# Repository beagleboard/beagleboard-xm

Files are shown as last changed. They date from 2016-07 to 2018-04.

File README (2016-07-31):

BeagleBoard-xM delivers extra ARM ® Cortex TM -A8 MHz now at 1 GHz and extra memory with 512MB of low-power DDR RAM, enabling hobbyists, innovators and engineers to go beyond their current imagination and be inspired by the BeagleBoard.org community. Designed with the community inputs in mind, this open hardware design improves upon the laptop-like performance and expandability, while keeping at hand-held power levels. Direct connectivity is supported by the on-board four-port hub with 10/100 Ethernet, while maintaining a tiny 3.25" × 3.25" footprint.

Revision C3

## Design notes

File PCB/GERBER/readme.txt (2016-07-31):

CALCAD, INC.
1600 E.PIONEER PARKWAY
SUITE # 530
ARLINGTON, TX 76010-6542
VOICE: (817)695.1806
FAX:   (817)695.1809
E-MAIL: pcb@calcad.net

CUSTOMER: CIRCUITCO
E.E. CONTACT: RAO
DATE: 08-17-2011
JOB NAME:BeagleBoard_xM_Revc1.BRD 
FAB.#: BEAGLE XM

	  FILE DESCRIPTIONS :

		 CCAM/GERBER/xM_RevC1_*:   = GERBER DATA
                      
                                     lyr1.ART  = TOP SIDE     LYR 1
                                     lyr2.ART  = GND PLANE    LYR 2
                                     lyr3.ART  = INNER SIGNAL LYR 3
                                     lyr4.ART  = INNER SIGNAL LYR 4
                                     lyr4.ART  = PWR PLANE    LYR 5
                                     lyr4.ART  = BOTTOM SIDE  LYR 6
                                     tslk.ART  = TOP SIDE SILKSCREEN
                                     bslk.ART  = BOTTOM SIDE SILKSCREEN
                                      smc.ART  = TOP SIDE SOLDERMASK
                                      sms.ART  = BOT SIDE SOLDERMASK
                                      spc.ART  = TOP SOLDERPASTE SCREEN
                                      sps.ART  = BOTTOM SOLDERPASTE SCREEN                                                                 
   
		   DRILL/*:   *NCDRILL*.TAP  = DRILL DATA

                         	  NCDRILL.LOG  = HOLE SIZES AND COUNT
			         NC_PARAM.TXT  = DRILL PARAMETER FILE                                                
                  
                    CCAM/*.CAD  = ASCII CAD FILE
                                                             
                    DXF/*.DXF  = DXF DRAWING FILE(S)

                    PDF/*.PDF  = ACROBAT DRAWING FILE(S)

                    *_XY.CMP  = COMPONENT X-Y LIST

                    *_IPC356A.IPC  = IPC-D-356A NETLIST EXTRACT

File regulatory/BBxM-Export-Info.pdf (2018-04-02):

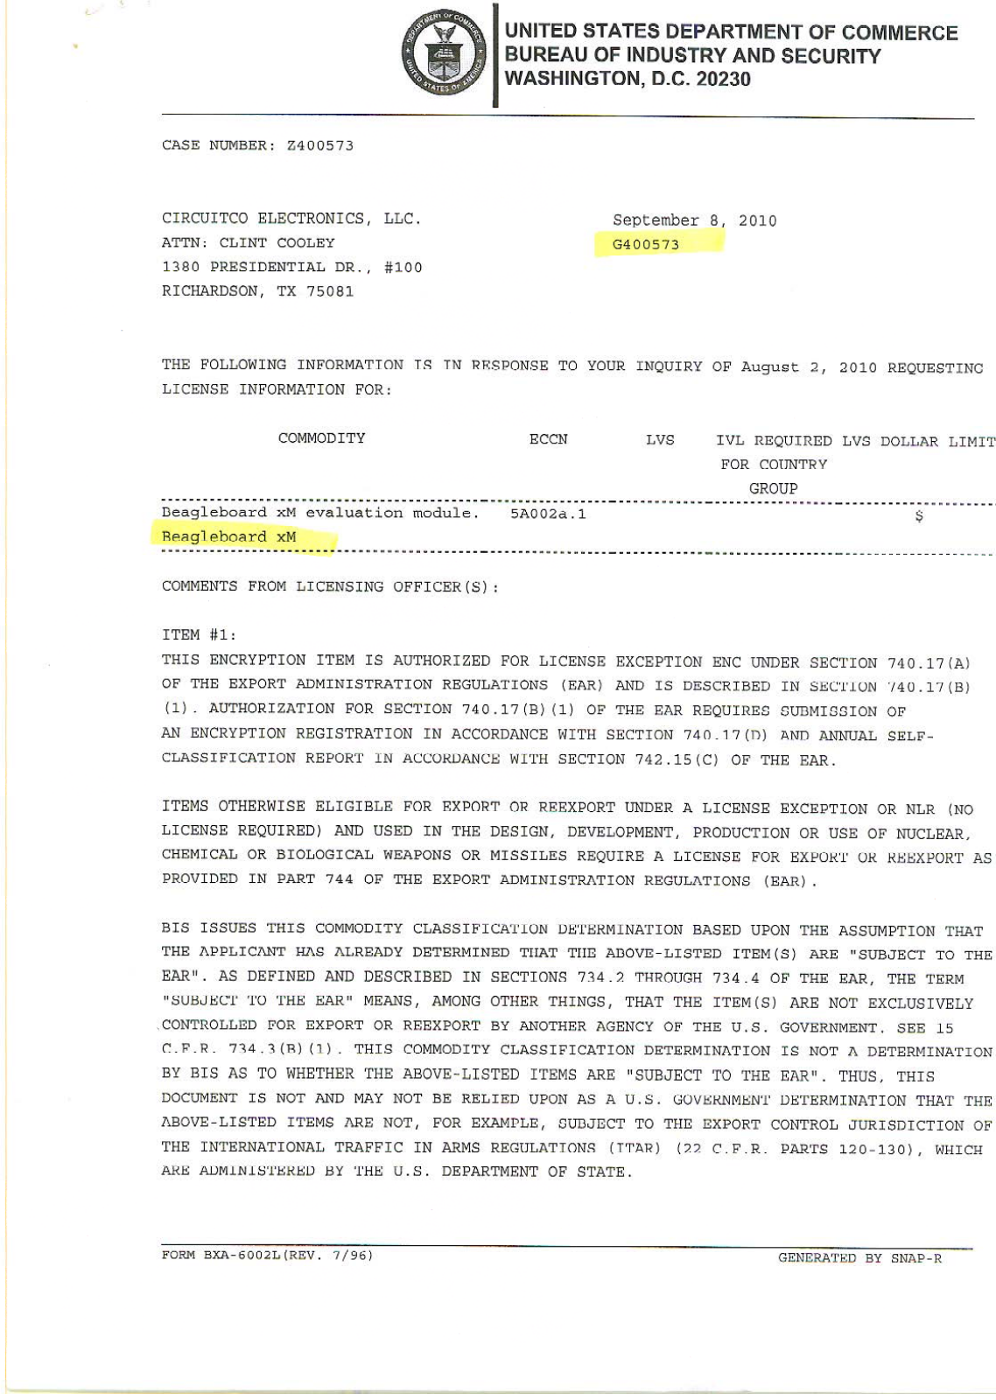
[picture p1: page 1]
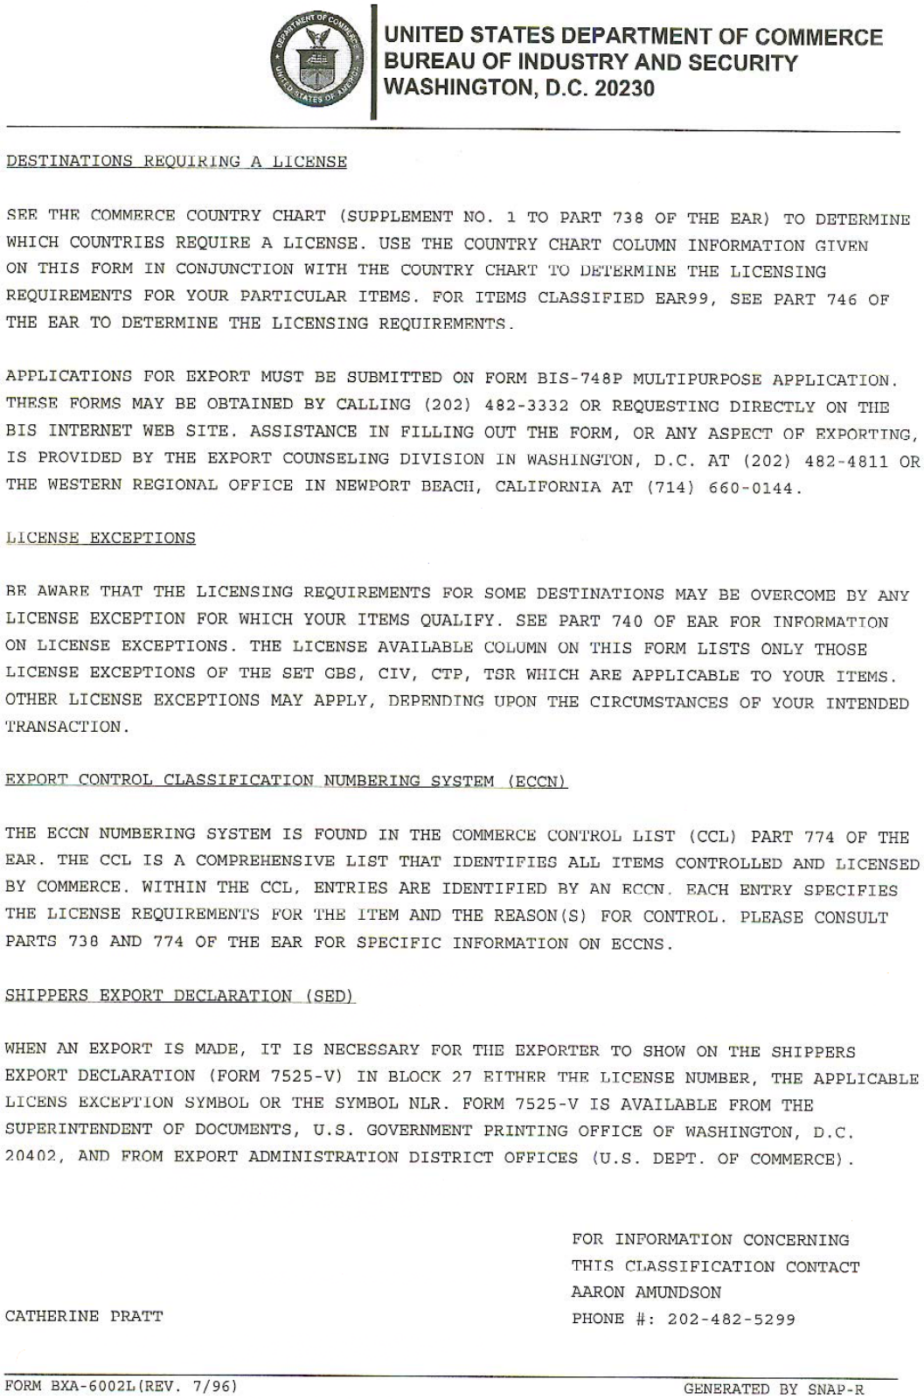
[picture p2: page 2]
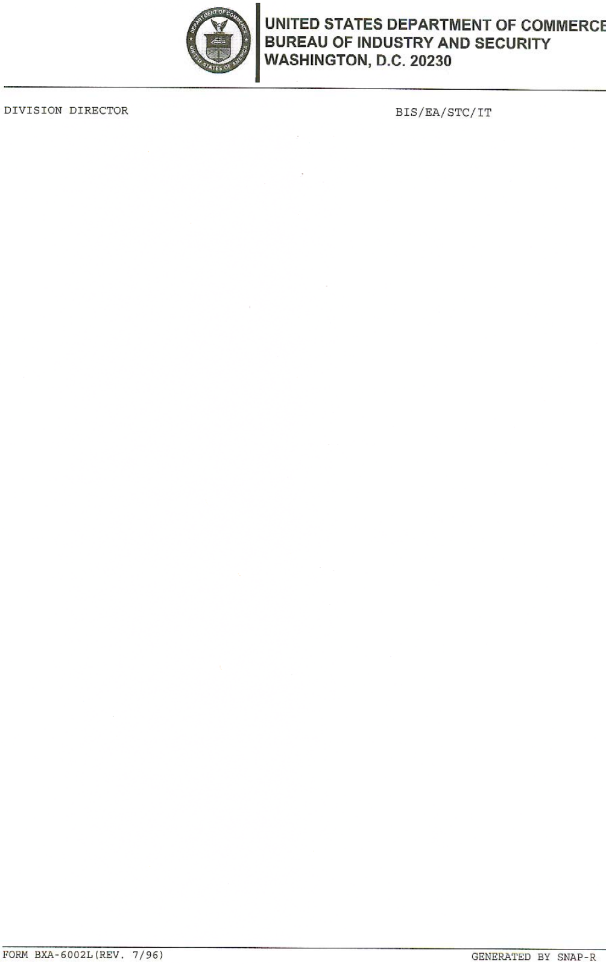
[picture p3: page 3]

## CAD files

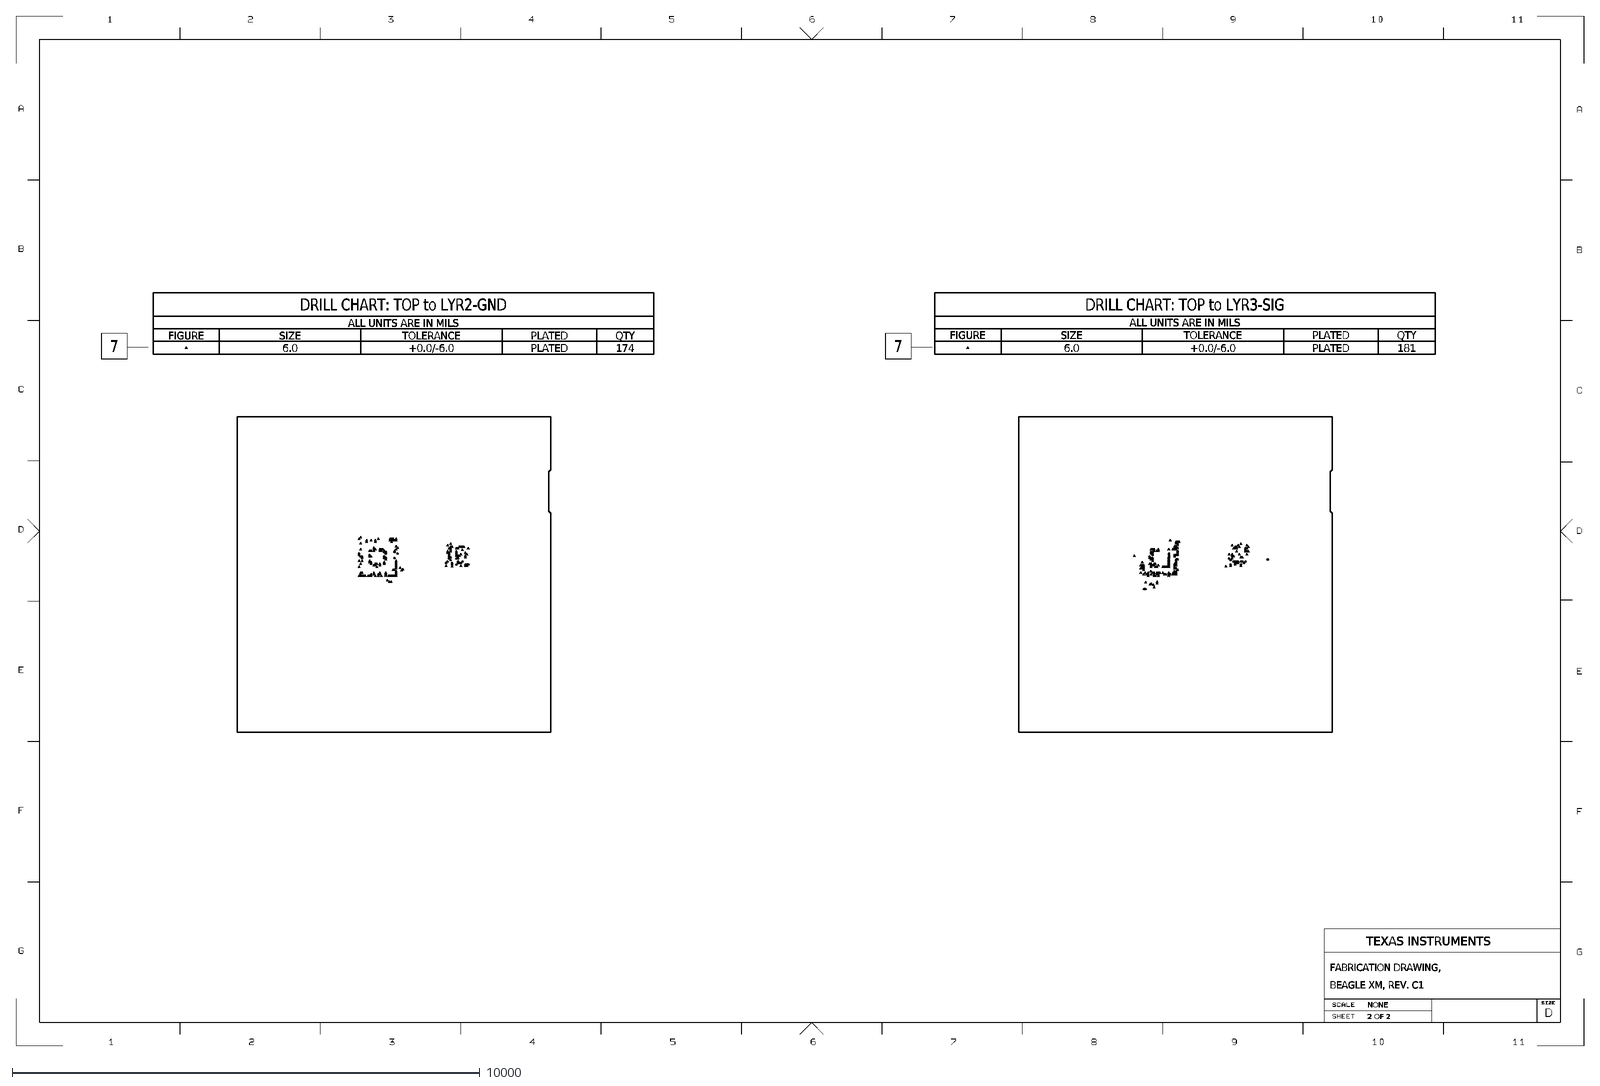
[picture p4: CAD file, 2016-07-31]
PCB/GERBER/DXF/BeagleBoard_xM_RevC1_RevC1_FAB2.dxf
TEXAS INSTRUMENTS
FABRICATION DRAWING,
BEAGLE XM, REV. C1
2 OF 2
181
QTY
PLATED
+0.0/-6.0
TOLERANCE
ALL UNITS ARE IN MILS
DRILL CHART: TOP to LYR3-SIG
6.0
SIZE
FIGURE
174
DRILL CHART: TOP to LYR2-GND
7
NONE

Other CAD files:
PCB/GERBER/DXF/BeagleBoard_xM_RevC1_ASSY1.dxf
PCB/GERBER/DXF/BeagleBoard_xM_RevC1_ASSY2.dxf
PCB/GERBER/DXF/BeagleBoard_xM_RevC1_RevC1_FAB1.dxf

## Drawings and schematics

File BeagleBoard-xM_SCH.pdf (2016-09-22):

5 | 4
D | D
C | C
B | B
A | A

# Title

Size | Document Number | Rev
Date: | Sheet | of
| 450-5100-001 | C

# BeagleBoard-xM Cover Page

B
Tuesday, January 11, 2011 | 1 | 10

# Title

# BeagleBoard-xM Cover Page

Tuesday, January 11, 2011 | 1 | 10

# Title

# BeagleBoard-xM Cover Page

Tuesday, January 11, 2011 | 1 | 10
REV | DESCRIPTION | DATE BY

A
8/31/09 GC

# FEATURE CHANGES

1. Added 4 port LS/FS/HS HUB to provide four USB Host ports.
2. Made connection for the 1.8V rail on the USB PHY to go to VAUX2.

# 3. Added camera connector that is compatible to the Leopard Imaging Camera

modules.

# 4. Added power rmanagement capabilities to allow shut dowm of serial port, DVI-D, and

power LED.
5. Switched to DM3730 processor and 512MB memory.
6. Added ability to turn off 26MHZ oscillator.
7. Increased overall board size to accomodate the changes.
8. Changed serial connector to a female DB9.
9. Added a 10/100 Ethernet port.

A1

# 1. Disabled the DVI-D powerdown due to use of wrong GPIO pin. Pin is in the MMC

group and it cannot be switched to 1.8V without impacting the SD card slot.

# 2. Disables HUB reset due to a timing issue with SW. When active the LAN9514

would not work correctly and the Ethernet function is broken.

5/13/10

GC

# 1. Changed C9 to DNI and changed R34, 4.7K to installed to enable the S-Video

operation. A2 | 6/15/10 GC

NO MAJOR FEATURE CHANGES.
1. PCB Layout changes.
2. Added R157 in series with MMC2_CLK.
3. Added R158 to isolate shunt FET to reduce power in DC mode.
4. Added optional pullup resistors on I2C2_SCL and I2C_SDA into the layout.

# 5. Moved DVI_PUP signal to TPS65950. Previous location could not be used due to a

conflict with the MMC function on the pins.

A3

6/23/10 GC

# CONTENTS

8

1

# MICROSD, RS232,CAMERA,EXPANSION

9

3

2

# USB HOST, HUB, ETHERNET

# DVI-D, LCD EXPANSION

10

# PMIC, POWER RAILS

# PROCESSOR 2 OF 3, JTAG, SWITCHES, LEDS, SVIDEO

7

# PMIC, AUDIO JACKS, CLOCKS

PAGE NO. | SCHEMATIC PAGE

# PROCESSOR 3 OF 3

# PROCESSOR 1 OF 3

4

# USB OTG CONNECTOR AND MAIN POWER

5

# COVER PAGE

6

# This schematic is *NOT SUPPORTED* and DOES NOT constitute a reference design. Only “community” support is allowed

via resources at BeagleBoard.org/discuss.

# THERE IS NO WARRANTY FOR THIS DESIGN , TO THE EXTENT PERMITTED BY APPLICABLE LAW. EXCEPT WHEN OTHERWISE STATED IN WRITING THE COPYRIGHT HOLDERS AND/OR OTHER PARTIES

PROVIDE THE DESIGN “AS IS” WITHOUT WARRANTY OF ANY KIND,

# EITHER EXPRESSED OR IMPLIED, INCLUDING, BUT NOT LIMITED TO, THE IMPLIED WARRANTIES OF MERCHANTABILITY AND FITNESS FOR A PARTICULAR PURPOSE. THE ENTIRE RISK AS TO THE QUALITY AND PERFORMANCE OF THE DESIGN IS WITH YOU. SHOULD THE DESIGN DESIGN PROVE DEFECTIVE, YOU ASSUME THE COST OF

ALL NECESSARY SERVICING, REPAIR OR CORRECTION.

B
10/26/2010 GC

NO MAJOR FEATURE CHANGES.
1. Changed DM3730 from an ES1.0 to a ES1.1.

C

12/7/2010 GC

# REPLACED OVERVOLTAGE CIRCUIT

1. Deleted U19, U31, and U32.
2. Deleted C214 and C212.
3. Added new U31 and U32, a NCP349MNAE overvoltage protection device.

# ADDED DC POWER DETECTION

1. Moved Q2A to level shift nUSB_PWR.

# 2. Connected Q2A output to the TPS65950 GPIO as indication that the board is DC

powered when LOW.
CHANGED SD CONNECTOR DUE TO EOL OF CURRENT PART.
1. Replaced uSD connector with new part number.
2. Delete C188, R131, R133,R132,R134,R152,R153,R15,R144,R120,C211.

# CHANGED PROCESSOR TO ES1.2 CHANGED USB HUB DEFAULT MODE

1. Changed DC control of HUB to come up OFF. Requires SW to activate.

D | D
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

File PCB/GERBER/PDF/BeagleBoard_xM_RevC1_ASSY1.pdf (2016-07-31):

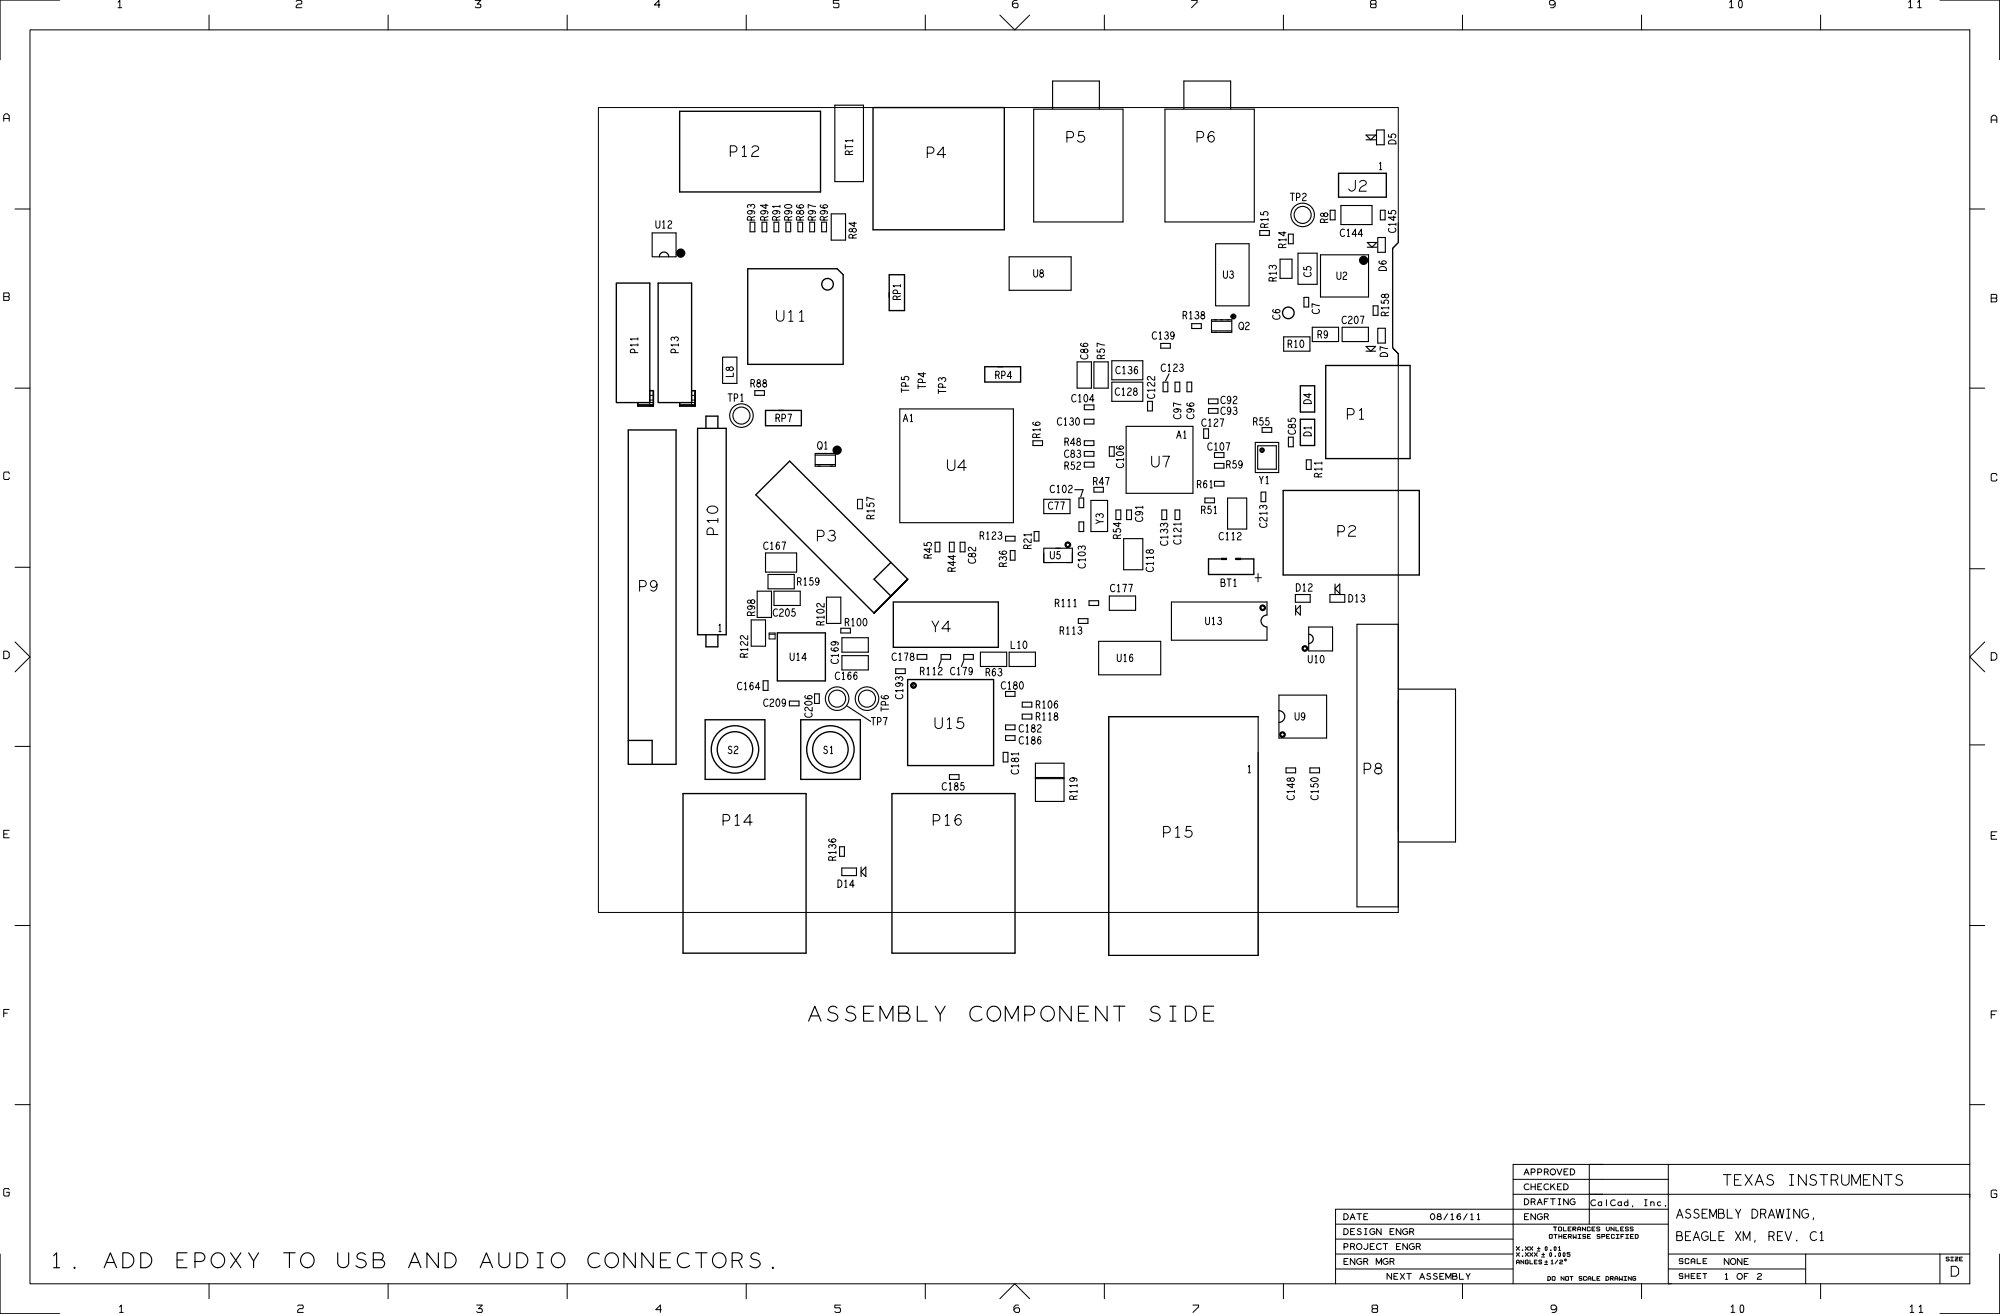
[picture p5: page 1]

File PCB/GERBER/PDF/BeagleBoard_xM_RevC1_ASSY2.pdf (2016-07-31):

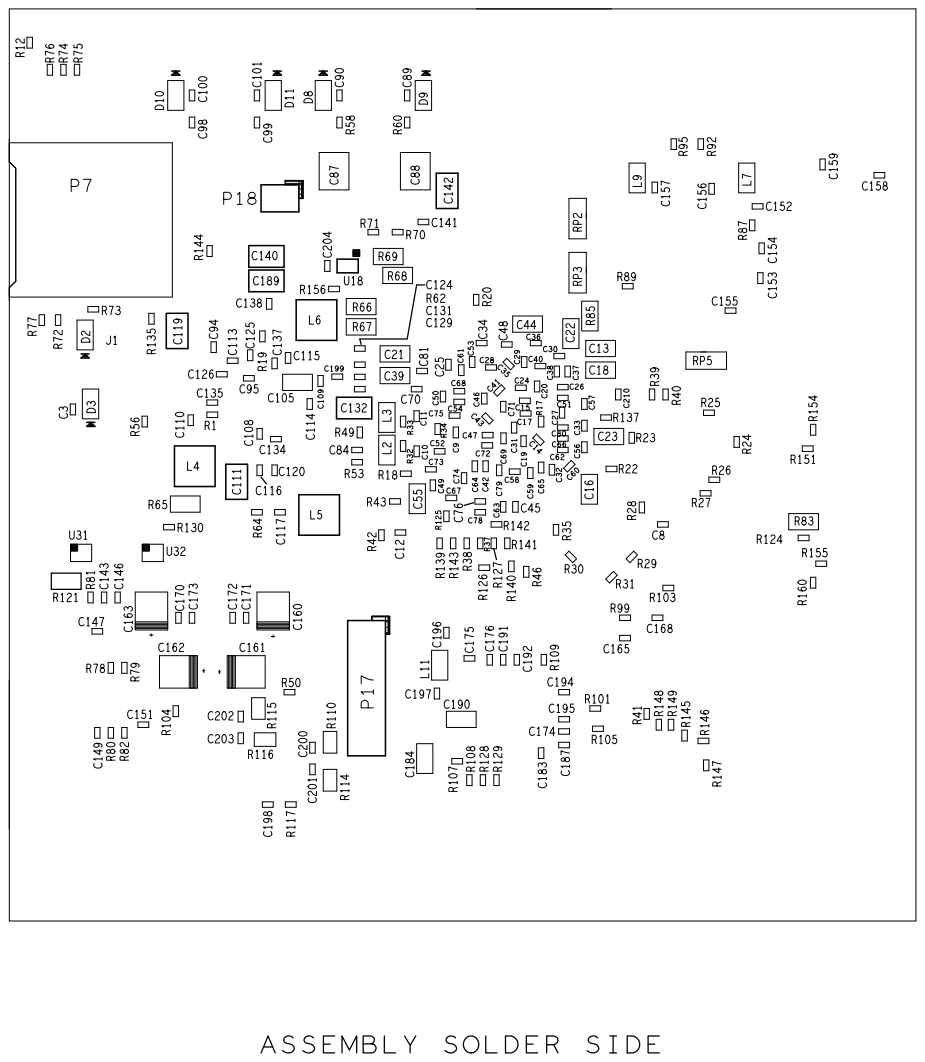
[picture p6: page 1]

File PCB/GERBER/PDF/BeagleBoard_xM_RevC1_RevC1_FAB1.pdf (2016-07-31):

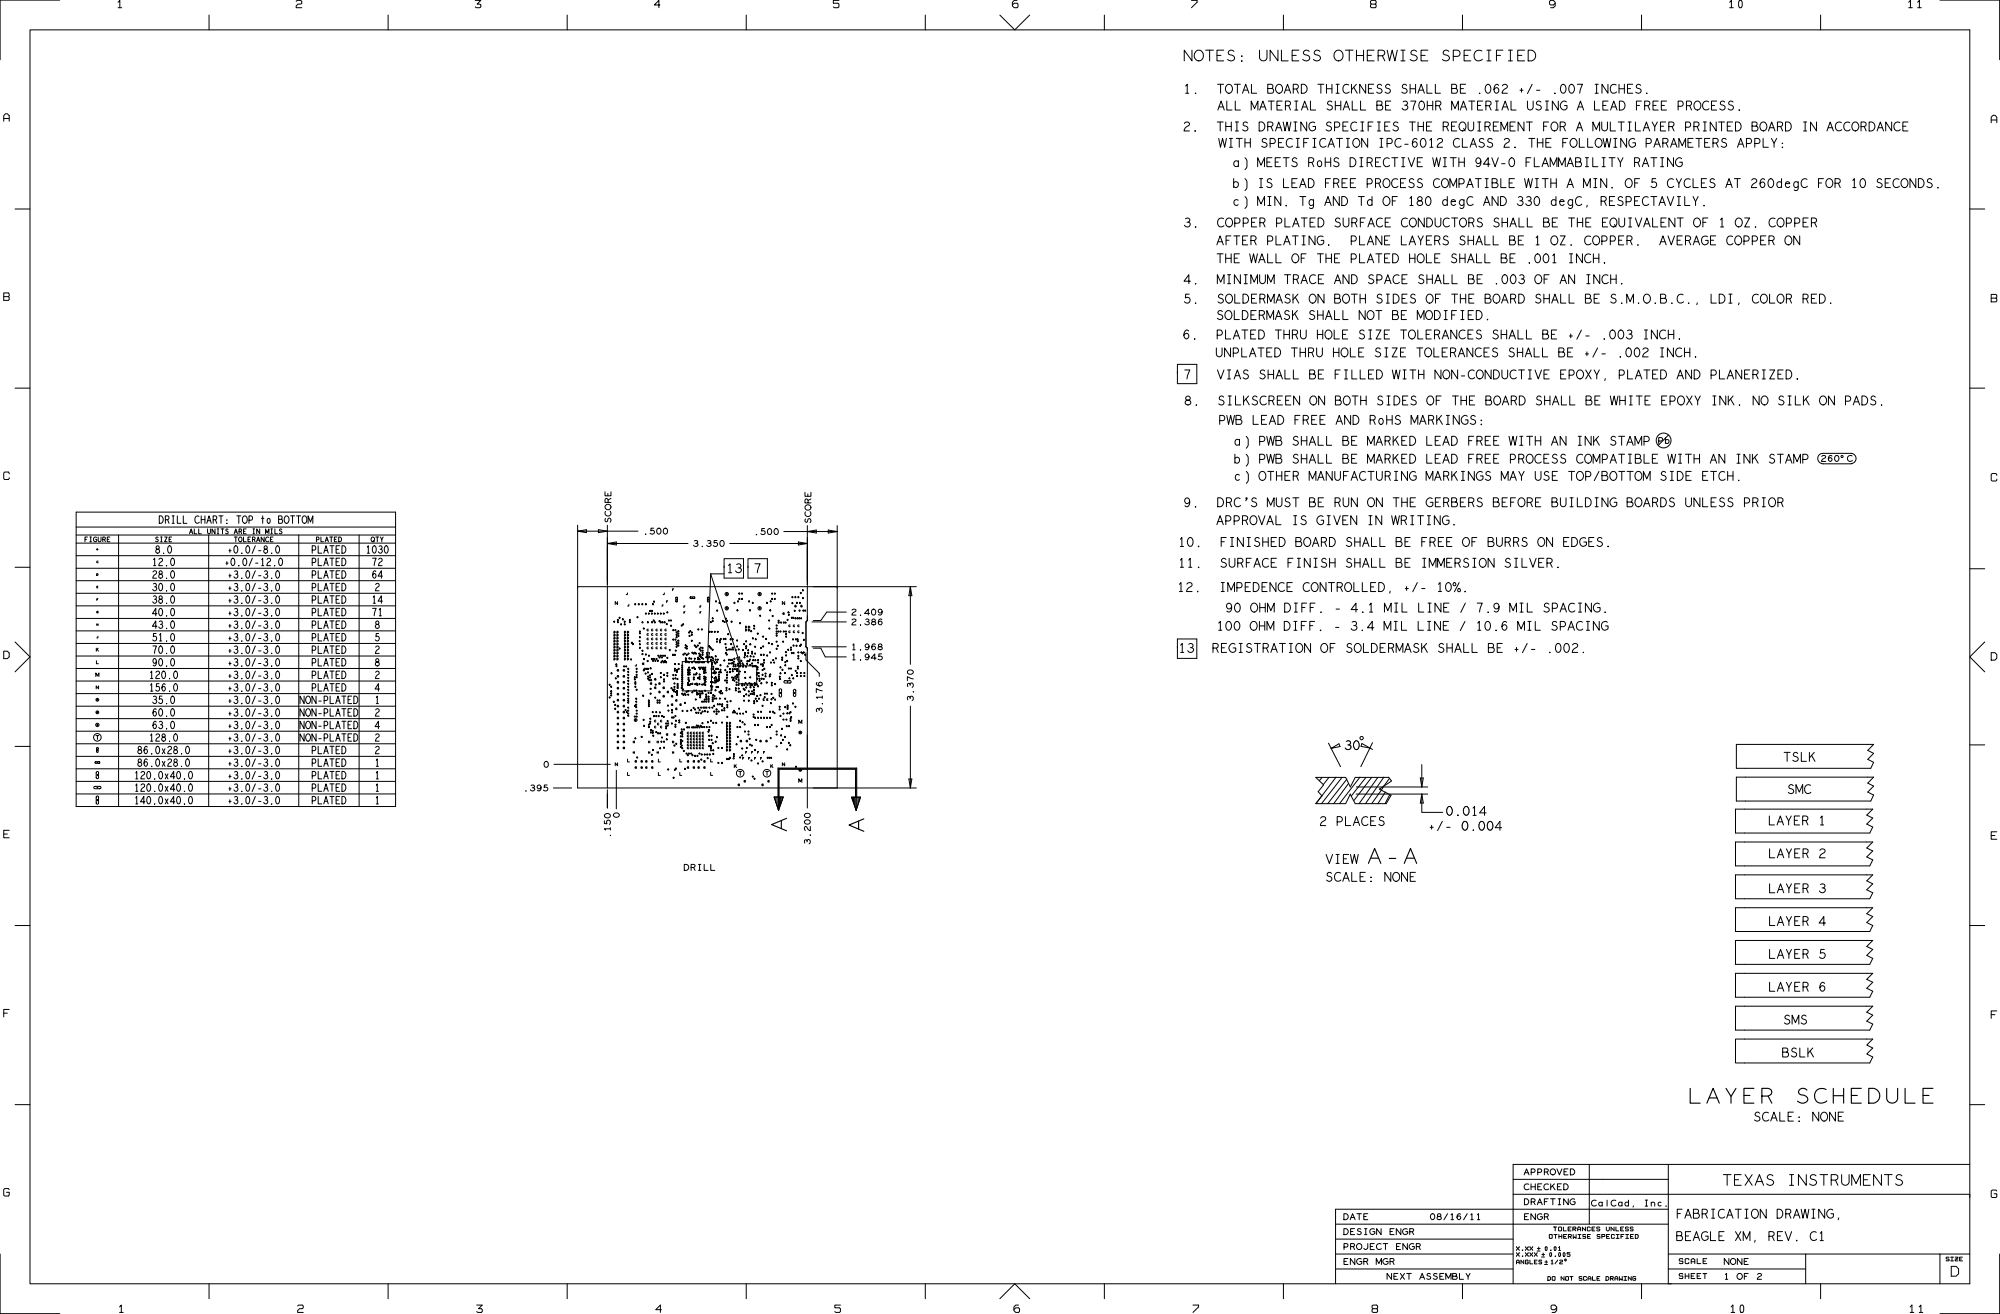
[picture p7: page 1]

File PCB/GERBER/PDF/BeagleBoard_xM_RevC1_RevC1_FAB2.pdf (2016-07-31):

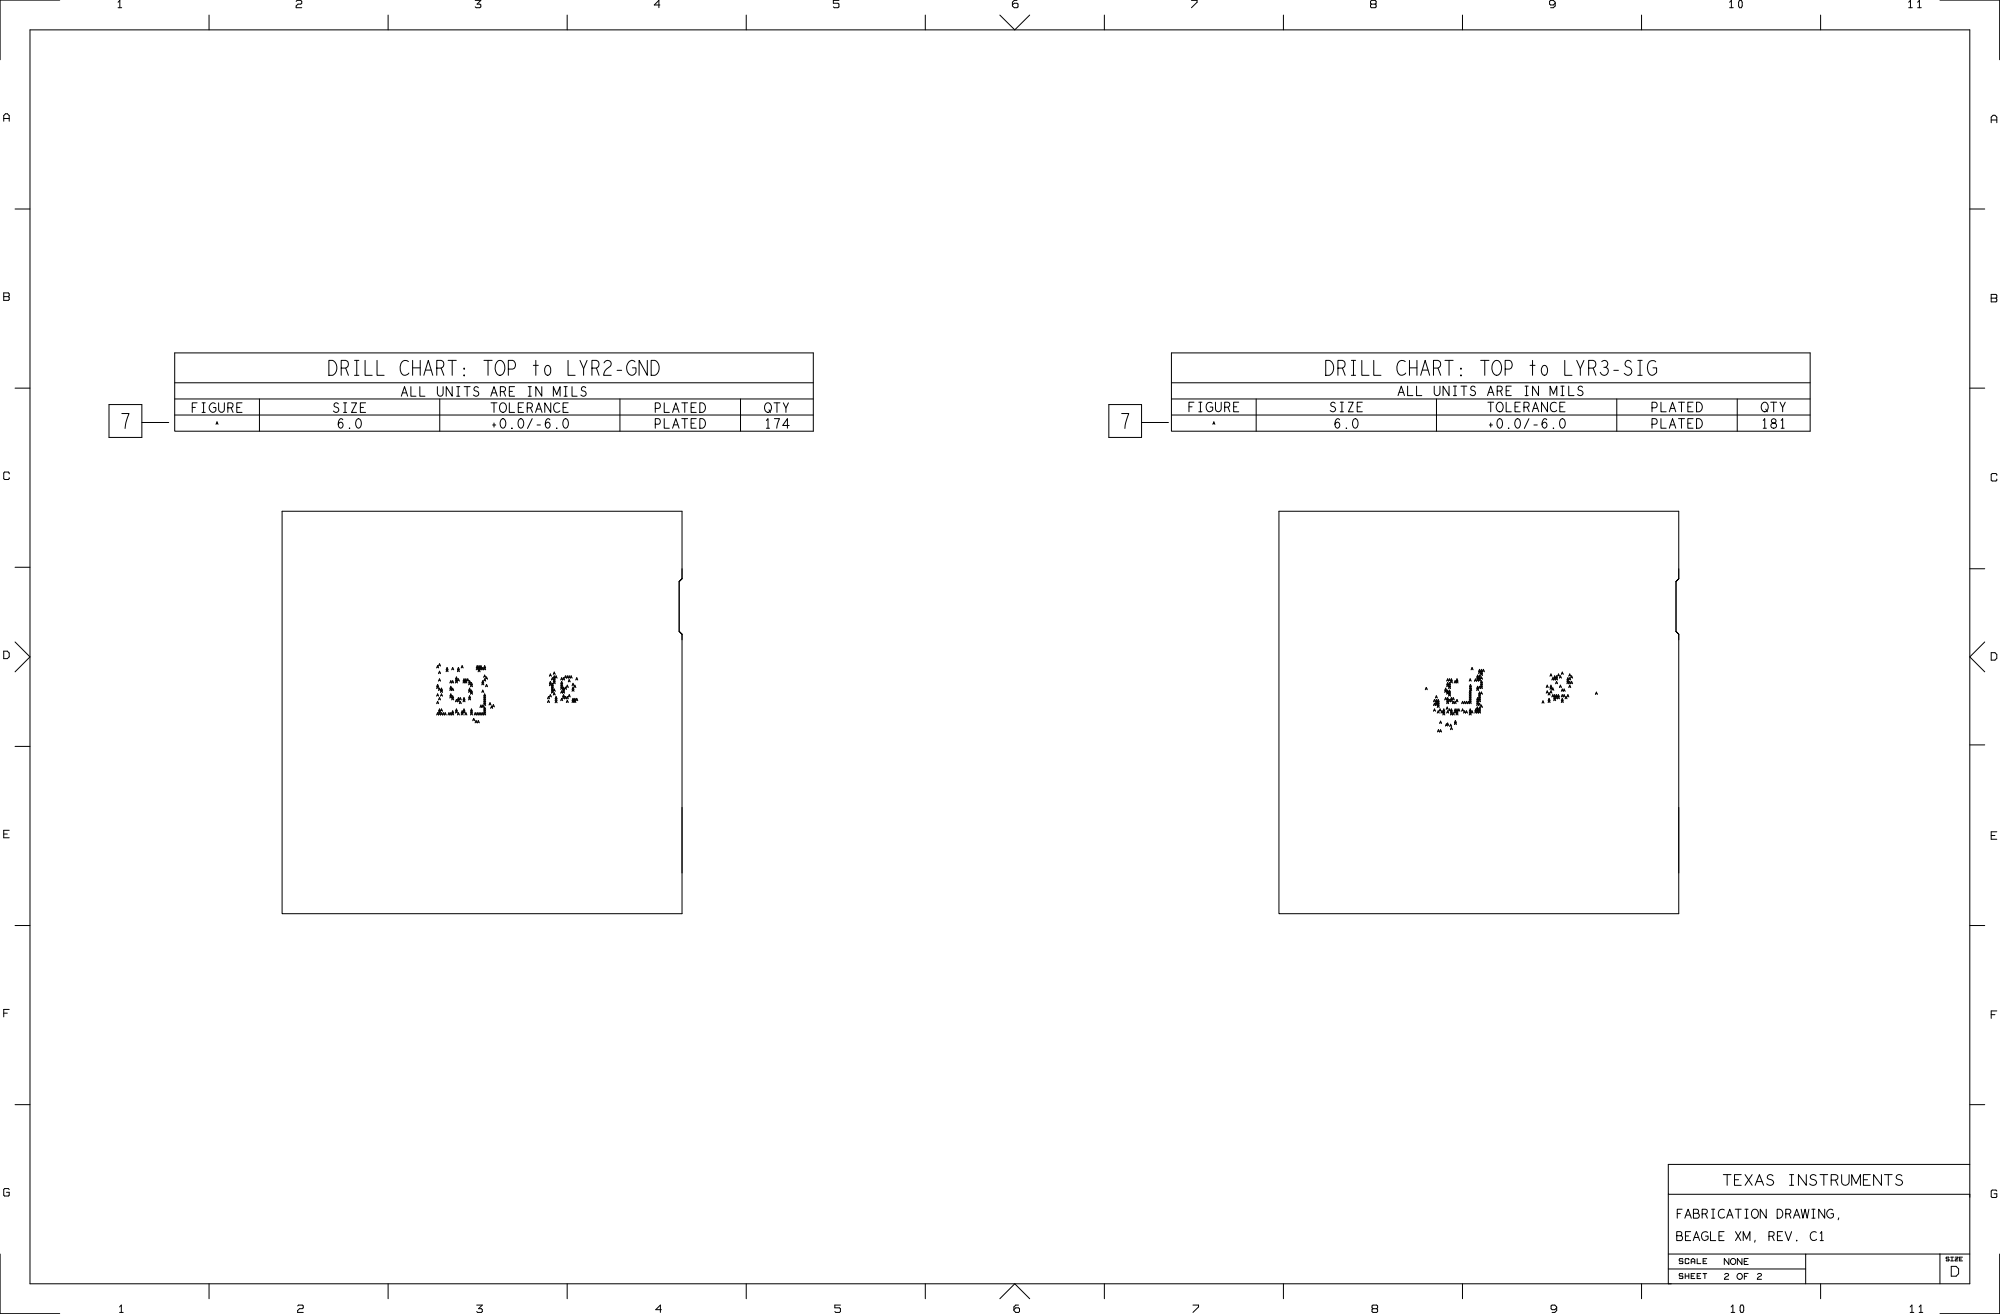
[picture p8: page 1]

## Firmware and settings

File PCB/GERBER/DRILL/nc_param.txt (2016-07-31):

INTEGER-PLACES         3
DECIMAL-PLACES         5
X-OFFSET               0.000000
Y-OFFSET               0.000000
FEEDRATE               1
COORDINATES            ABSOLUTE
OUTPUT-UNITS           ENGLISH
TOOL-ORDER             INCREASING
REPEAT-CODES           YES
SUPPRESS-LEAD-ZEROES   NO
SUPPRESS-TRAIL-ZEROES  NO
SUPPRESS-EQUAL         NO
TOOL-SELECT            YES
OPTIMIZE_DRILLING      NO
ENHANCED_EXCELLON      YES
HEADER                 none
LEADER                 12
CODE                   ASCII
SEPARATE               NO
DRILLING               LAYER-PAIR
BACKDRILL              NO

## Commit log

2016-07-31 Expand archives
    [BEAGLE-xM_ORCAD_REVC.DSN, art_param.txt, nc_param.txt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]
2016-07-31 Rename files and directories
    [BeagleBoard-xM_BOM.xls, art_param.txt, nc_param.txt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]
2016-07-31 Update to Rev C1
    [BeagleBoard_xM_RevC1_ASSY1.dxf, BeagleBoard_xM_RevC1_ASSY2.dxf, BeagleBoard_xM_RevC1_RevC1_FAB1.dxf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]
2016-07-31 Update to Rev C2
    [BeagleBoard-xM_BOM.xls]
2016-07-31 Updated to revision C3
    Only change is a new memory device: MT46H128M32L2KQ-48 IT:C
    [BeagleBoard-xM_BOM.xls]
2016-09-15 BOM: More rev C3 changes
    Changed POP Memory Part number, changed PMIC part number, updated rev notes to C3 and small layout change to improve manufacturing yield.
    Layout change not yet checked-in.
    [BeagleBoard-xM_BOM.xls, BeagleBoard-xM_BOM.xlsx]
2016-09-22 Rotate schematic PDF
2016-09-22 Add Link-PP LPJ1026AGNL Ethernet jack
    [BeagleBoard-xM_BOM.xlsx]
